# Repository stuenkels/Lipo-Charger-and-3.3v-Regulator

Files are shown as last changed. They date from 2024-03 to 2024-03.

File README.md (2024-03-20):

# Lipo-Charger-and-3.3v-Regulator
Lipo battery charger with 3.3v fixed output. TP4056 IC used for charging. DWO1-A IC for battery protection, combined with the FS8205A dule mosfett chip. TPS63001 IC for fixed voltage regulation.

## 3d View
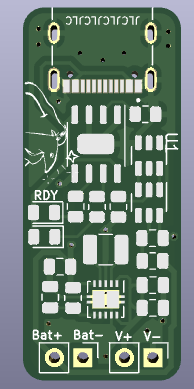
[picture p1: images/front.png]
Front

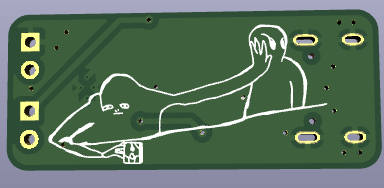
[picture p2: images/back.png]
Back


## Finished board
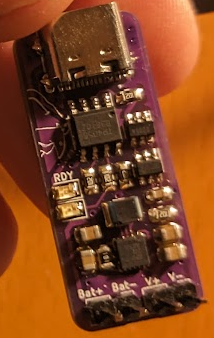
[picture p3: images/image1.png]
pcb


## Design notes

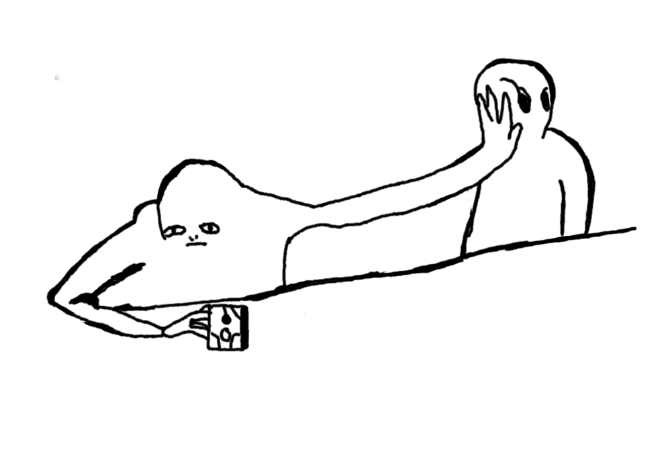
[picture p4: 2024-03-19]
Lipo Charger KiCad Files/board_art/back.png

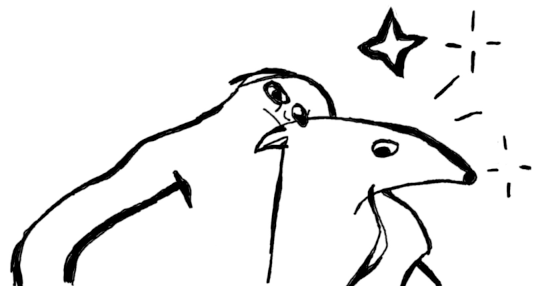
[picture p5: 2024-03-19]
Lipo Charger KiCad Files/board_art/frount.png

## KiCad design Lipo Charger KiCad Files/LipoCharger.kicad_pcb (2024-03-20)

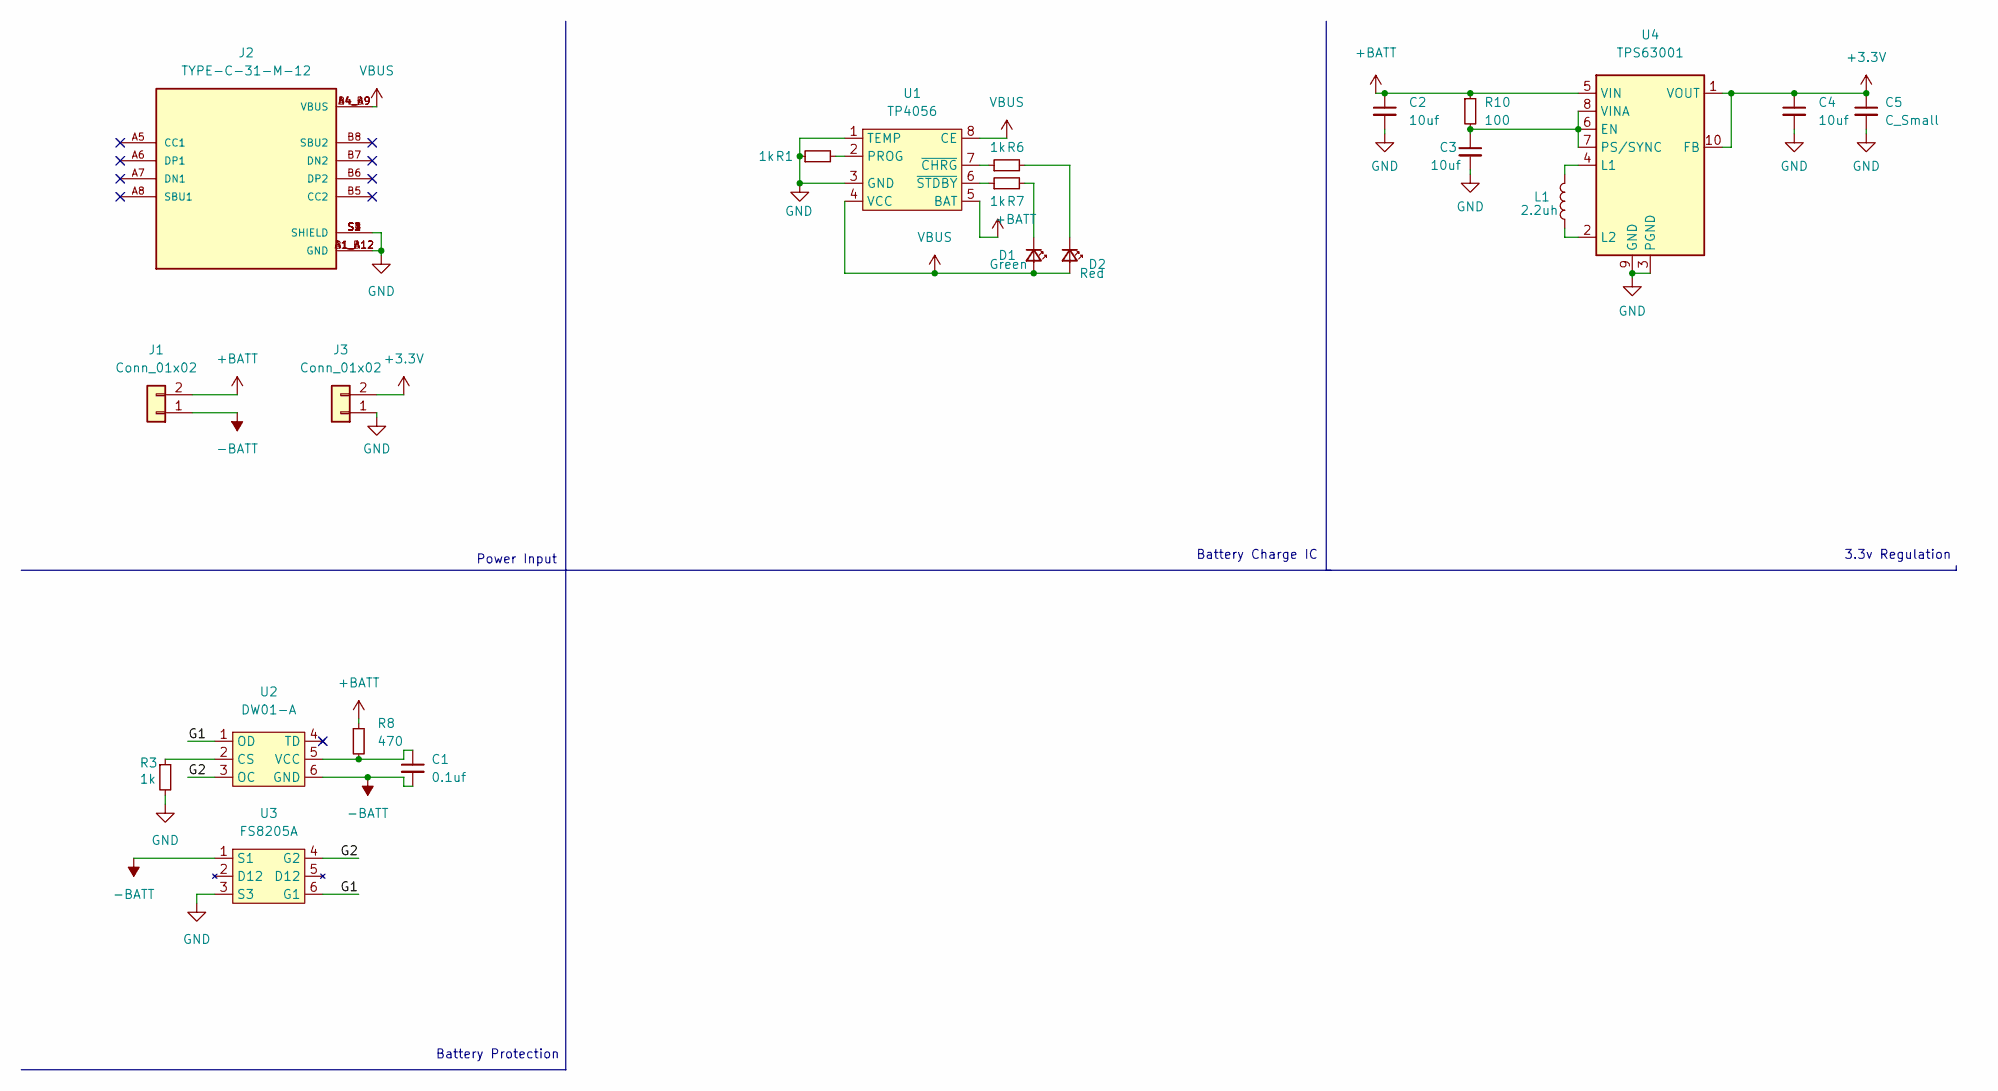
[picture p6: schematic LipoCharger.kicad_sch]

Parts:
C1: 0.1uf; C_0805_2012Metric
C2, C3, C4: 10uf; C_0805_2012Metric
C5: C_Small; C_0805_2012Metric
D1: Green; LED_0805_2012Metric
D2: Red; LED_0805_2012Metric
J1, J3: Conn_01x02; PinHeader_1x02_P2.54mm_Vertical
J2: TYPE-C-31-M-12; HRO_TYPE-C-31-M-12; PARTREV 2020.12.08
L1: 2.2uh; L_1210_3225Metric
R1, R3, R6, R7: 1k; R_0805_2012Metric
R8: 470; R_0805_2012Metric
R10: 100; R_0805_2012Metric
U1: TP4056
U2: DW01-A; SOT-23-6
U3: FS8205A; SOT-23-6
U4: TPS63001; Texas_DRC0010J_ThermalVias

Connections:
+3.3V: C4.1, C5.1, J3.2, U4.1 (VOUT), U4.10 (FB)
+BATT: C2.1, J1.2, R8.1, R10.1, U1.5 (BAT), U4.5 (VIN)
-BATT: C1.2, J1.1, U2.6 (GND), U3.1 (S1)
/G1: U2.1 (OD), U3.6 (G1)
/G2: U2.3 (OC), U3.4 (G2)
GND: C2.2, C3.2, C4.2, C5.2, J2.A1_B12 (GND), J2.B1_A12 (GND), J2.S1 (SHIELD), J2.S2 (SHIELD), J2.S3 (SHIELD), J2.S4 (SHIELD), J3.1, R1.1, R3.2, U1.1 (TEMP), U1.3 (GND), U3.3 (S3), U4.3 (PGND), U4.9 (GND), U4.11 (PGND)
unnamed: C1.1, R8.2, U2.5 (VCC)
unnamed: C3.1, R10.2, U4.6 (EN), U4.7 (PS/SYNC), U4.8 (VINA)
unnamed: D1.1 (K), R7.2
unnamed: D2.1 (K), R6.2
unnamed: L1.1, U4.2 (L2)
unnamed: L1.2, U4.4 (L1)
unnamed: R1.2, U1.2 (PROG)
unnamed: R3.1, U2.2 (CS)
unnamed: R6.1, U1.7 (~CHRG)
unnamed: R7.1, U1.6 (~STDBY)
VBUS: D1.2 (A), D2.2 (A), J2.A4_B9 (VBUS), J2.B4_A9 (VBUS), U1.4 (VCC), U1.8 (CE)

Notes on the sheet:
Battery Protection
Power Input
Battery Charge IC
3.3v Regulation

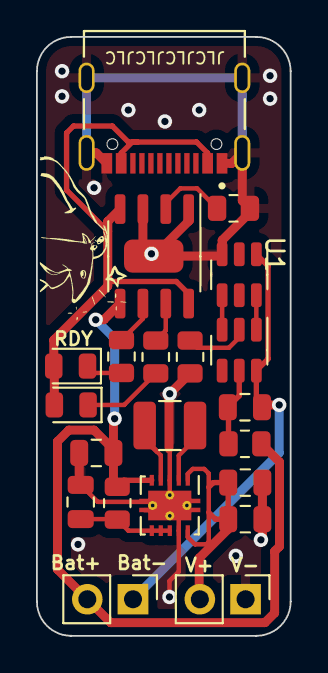
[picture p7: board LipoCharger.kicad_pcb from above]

Board: 2 copper layers, 14.1 x 33.3 mm, 21 parts (0 on the bottom side), 17 nets.

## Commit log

2024-03-19 initial file upload
    [LipoCharger.kicad_pcb, LipoCharger.kicad_sch]
2024-03-20 gerber and images
    [LipoCharger.kicad_pcb]
2024-03-20 fixed typo
    [LipoCharger.kicad_pcb, LipoCharger.kicad_sch]
